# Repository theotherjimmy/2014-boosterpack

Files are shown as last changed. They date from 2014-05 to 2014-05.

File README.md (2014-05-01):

2014-boosterpack
================
This repo contains the eagle source for a boosterpack designed for the Stellaris/Tiva lm4f/tm4c launchpads.

Features
================
* buck regulator circuit for bat -> vbus of launchpad
* headers for the launchpad
* motor driver circuit for driving two motors from battery power
* headers of power, ground, signal trios for ports B,D,E

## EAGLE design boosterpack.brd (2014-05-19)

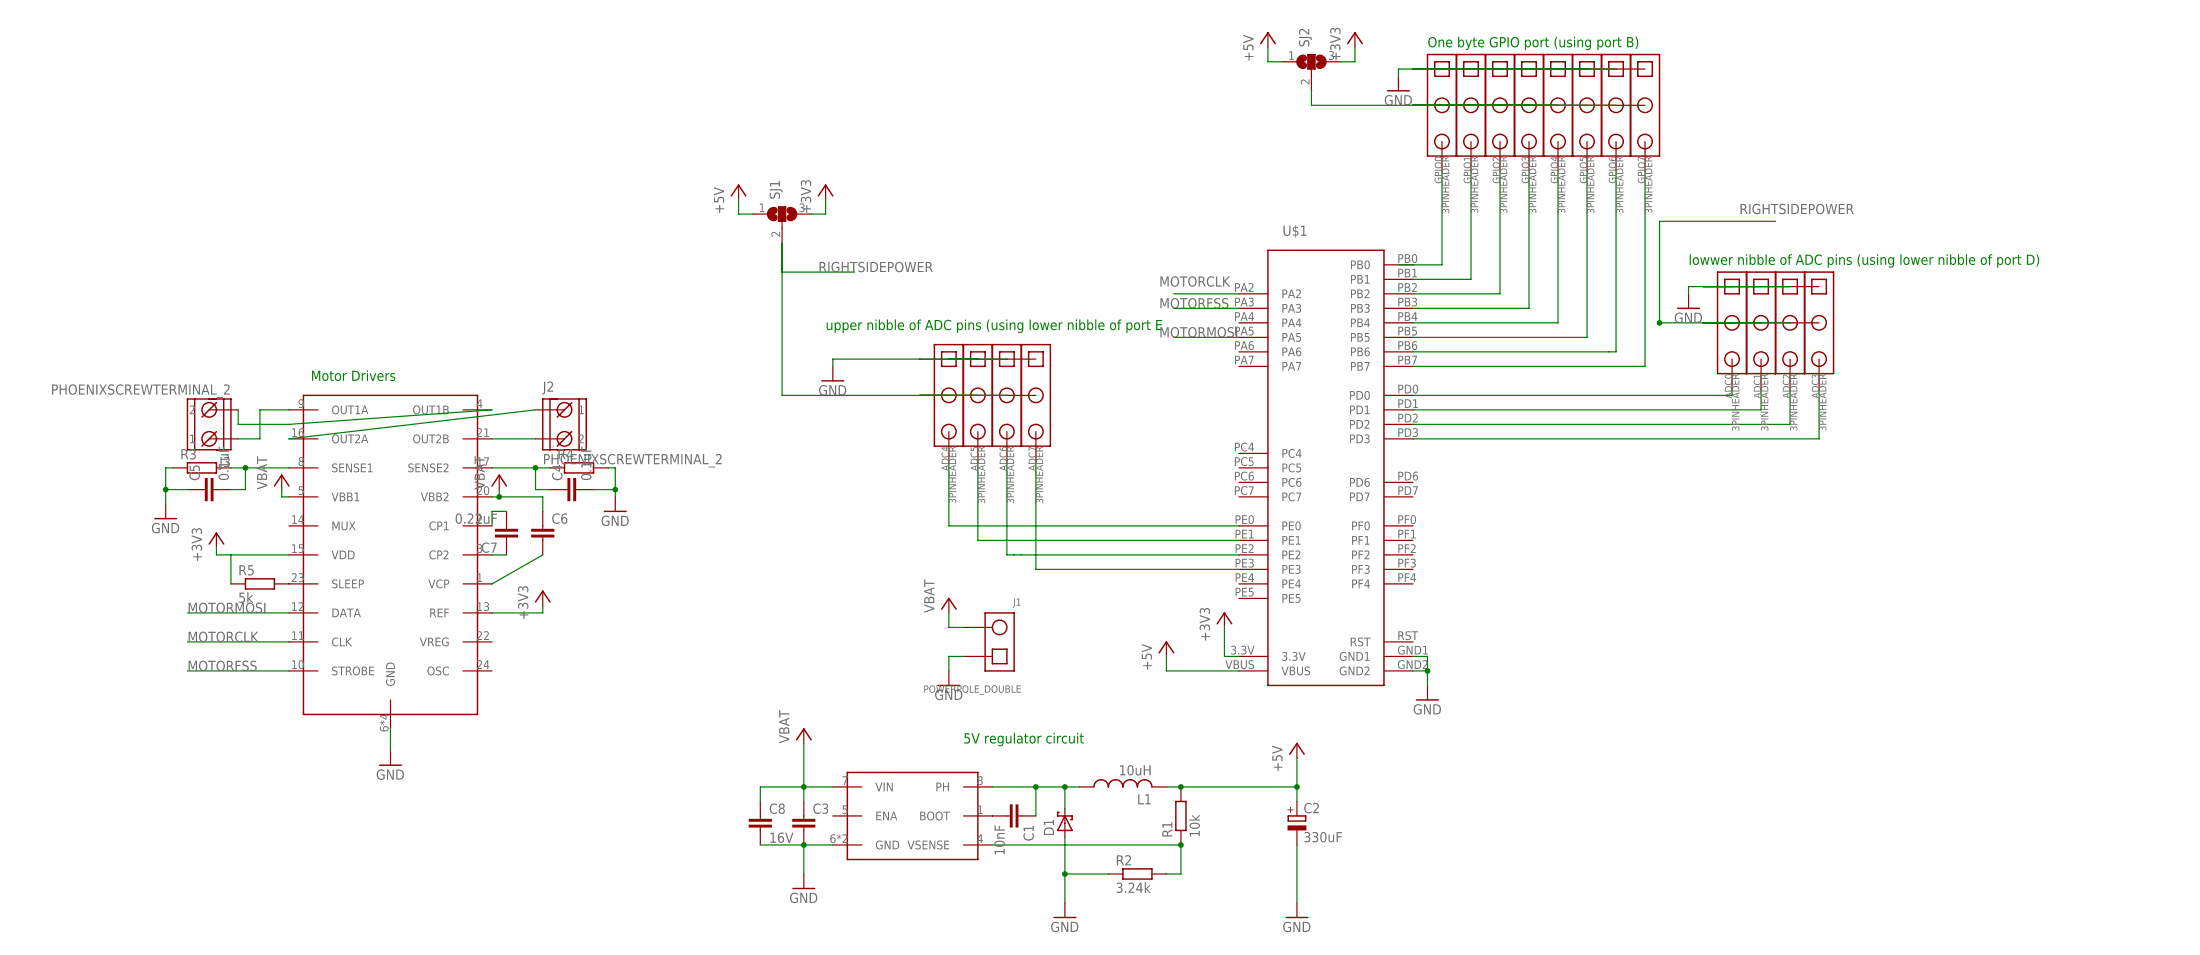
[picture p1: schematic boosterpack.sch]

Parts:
ADC0, ADC1, ADC2, ADC3, ADC4, ADC5, ADC6, ADC7: 3PINHEADER
C1: 10nF; C025-024X044
C2: 330uF; B45181B
C3: C-EU025-024X044; C025-024X044
C4, C5: 0.1uF; C025-025X050
C6: C-EU025-025X050; C025-025X050
C7: 0.22uF; C025-024X044
C8: 16V; C050-075X075
D1: SCHOTTKY-DIODEDO201T15; DO201T15
GPIO0, GPIO1, GPIO2, GPIO3, GPIO4, GPIO5, GPIO6, GPIO7: 3PINHEADER
J1: POWERPOLE_DOUBLE
J2, J3: PHOENIXSCREWTERMINAL_2
L1: 10uH; SDR1006
R1: 10k; 0204/7
R2: 3.24k; 0204/7
R3, R4: R-EU_0204/7; 0204/7
R5: 5k; 0204/7
SJ1, SJ2: SJ2W; SJ_2
U$1: STELLARIS-LAUNCHPADSTELLARIS-LAUNCHPAD-XL; LAUNCHPAD-XL
U$2: TPS5450; DDS
U$3: A3992A; DIP24

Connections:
+3V3: R5.1, SJ1.3, SJ2.3, U$1.3.3V, U$3.13 (REF), U$3.15 (VDD)
+5V: C2.+, L1.P$2 (2), R1.2, SJ1.1, SJ2.1, U$1.VBUS
ADC1: ADC1.3, U$1.PD1
ADC2: ADC2.3, U$1.PD2
ADC3: ADC3.3, U$1.PD3
ADC5: ADC5.3, U$1.PE1
GND: ADC0.1, ADC1.1, ADC2.1, ADC3.1, ADC4.1, ADC5.1, ADC6.1, ADC7.1, C2.-, C3.2, C4.2, C5.1, C8.2, D1.A, GPIO0.1, GPIO1.1, GPIO2.1, GPIO3.1, GPIO4.1, GPIO5.1, GPIO6.1, GPIO7.1, J1.1, R2.1, R3.1, R4.2, U$1.GND1, U$1.GND2, U$2.6 (GND), U$2.GROUNDPAD (GND), U$3.6 (GND), U$3.7 (GND), U$3.18 (GND), U$3.19 (GND)
GPIO0: GPIO0.3, U$1.PB0
GPIO1: GPIO1.3, U$1.PB1
GPIO2: GPIO2.3, U$1.PB2
GPIO3: GPIO3.3, U$1.PB3
MOTORCLK: U$1.PA2, U$3.11 (CLK)
MOTORFSS: U$1.PA3, U$3.10 (STROBE)
MOTORMOSI: U$1.PA5, U$3.12 (DATA)
unnamed: ADC0.3, U$1.PD0
unnamed: GPIO4.3, U$1.PB4
unnamed: GPIO5.3, U$1.PB5
unnamed: ADC6.3, U$1.PE2
unnamed: ADC7.3, U$1.PE3
unnamed: GPIO6.3, U$1.PB6
unnamed: GPIO0.2, GPIO1.2, GPIO2.2, GPIO3.2, GPIO4.2, GPIO5.2, GPIO6.2, GPIO7.2, SJ2.2
unnamed: GPIO7.3, U$1.PB7
unnamed: C1.2, U$2.1 (BOOT)
unnamed: R1.1, R2.2, U$2.4 (VSENSE)
unnamed: C1.1, D1.C, L1.P$1 (1), U$2.8 (PH)
unnamed: ADC4.3, U$1.PE0
unnamed: J3.2, U$3.4 (OUT1B)
unnamed: J3.1, U$3.9 (OUT1A)
unnamed: J2.1, U$3.16 (OUT2A)
unnamed: J2.2, U$3.21 (OUT2B)
unnamed: C5.2, R3.2, U$3.8 (SENSE1)
unnamed: C4.1, R4.1, U$3.17 (SENSE2)
unnamed: C6.2, U$3.1 (VCP)
unnamed: R5.2, U$3.23 (SLEEP)
unnamed: C7.1, U$3.3 (CP2)
unnamed: C7.2, U$3.2 (CP1)
RIGHTSIDEPOWER: ADC0.2, ADC1.2, ADC2.2, ADC3.2, ADC4.2, ADC5.2, ADC6.2, ADC7.2, SJ1.2
RST: U$1.RST
VCC: C3.1, C6.1, C8.1, J1.2, U$2.7 (VIN), U$3.5 (VBB1), U$3.20 (VBB2)

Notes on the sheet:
One byte GPIO port (using port B)
lowwer nibble of ADC pins (using lower nibble of port D)
upper nibble of ADC pins (using lower nibble of port E
5V regulator circuit
Motor Drivers

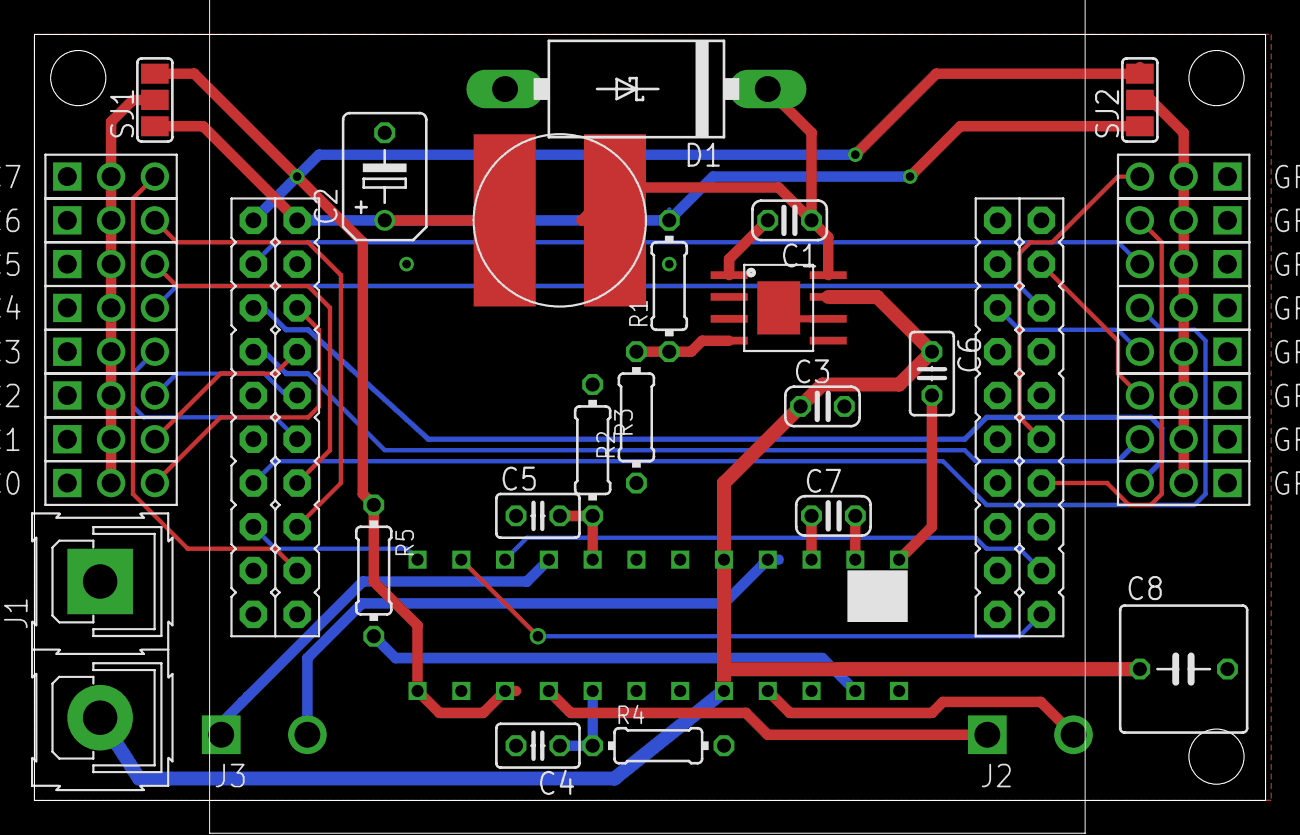
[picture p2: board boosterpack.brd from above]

Board: 2 copper layers, 71.4 x 44.4 mm, 39 parts (0 on the bottom side), 38 nets.

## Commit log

2014-04-30 moved a resistor that was bothering me
    [boosterpack.brd]
2014-05-03 shrank the board; added decopling cap for power
    [boosterpack.brd, boosterpack.sch]
2014-05-03 had @cmonr look at it; implemented suggestions
    [boosterpack.brd, boosterpack.sch]
2014-05-05 tidied up gerbers
    [boosterpack.brd]
2014-05-05 fixed collision in Power labeling and battery connector
    [boosterpack.brd]
2014-05-19 increased the spacing between the leads of all resistors and some caps
    [boosterpack.brd, boosterpack.sch]
